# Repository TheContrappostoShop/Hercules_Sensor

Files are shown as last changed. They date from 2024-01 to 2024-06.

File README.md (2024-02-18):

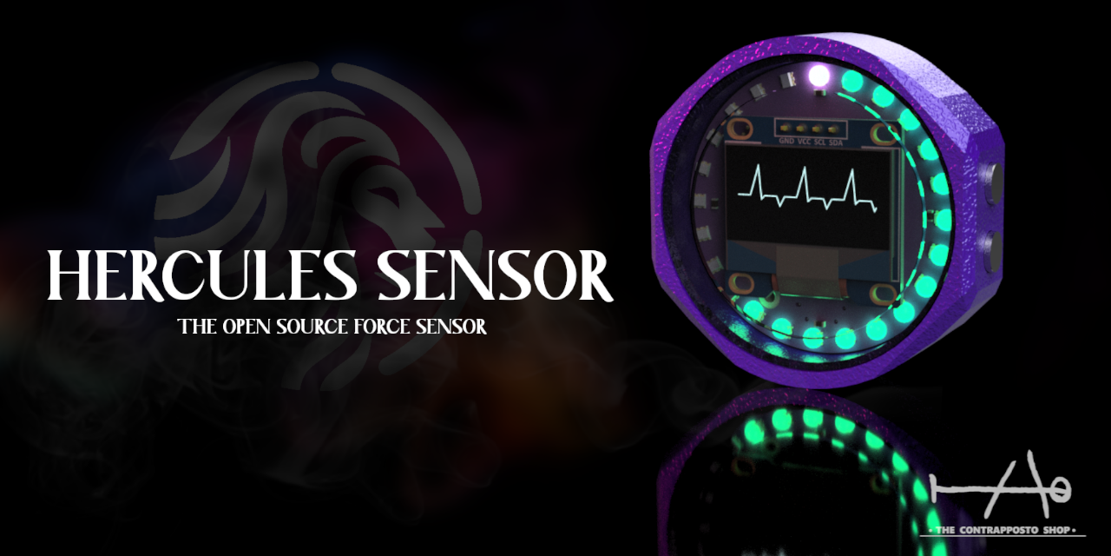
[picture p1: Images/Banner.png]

# Hercules Force Sensor Discord Link (https://discord.gg/GFUn9gwRsj)


Hercules is the open-source force sensor made for the Prometheus mSLA, based on the idea of Nico Martin (Concepts3D).

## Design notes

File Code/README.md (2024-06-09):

**This code is only for example and research purposes. It contains very simple routine to scale the graph and a simple peel detection algorithm. It can be serve to use the Hercules sensor "stand alone" because it will be integrated in our OS "Odyssey".**

How it works:

To calibrate the load cell the user needs to long press the screen then a calibration procedure will appear. A short press of the screen will zero out (tare) the current value.
After a few cycles the microcontroller will average the peak values of each peeling detection ( the number will be set at the top right corner ). The value at the top left is the real time value detected.
After a certain ammount of peel detected the scale is updated. The ''0'' value will zero out so the scale doesnt drift after a few layers of printing. It means that it will not take in account the weight of the parts on the build plate. 
The LED ring light represents the forces in real time. The 0 position represents the ''normal'' state and the end of the ring light (+100%) represents the max value of the graph (based on the average top right value).

**The peeling algorithm**

For now the few tests we did look promising even with this super simple algorithm. A threshold value is set just above the 0 line. When a peak is detected and the value returns close to 0 the peel detection is done.
*Sometimes with larger cross sections the peeling is done in stages and its probable that you will have multiple peaks. The treshold value is there so you are not detecting a wrong peel. Also there is a little waiting time (0.5sec) to see if the value is rising up signifying that the peel is not done yet.
When the sensor will be linked with Odyssey, we will be able to send commands both ways. It means that we will have something like ''wait for peel'' so the peeling will be in sink with the printer states.

User parameters Of the sensor:

-How many load cell ( if the sensor is used alone we suggest to use only one because processing all the numbers and calculations will slow down the microcontroller. Later all the calculation will be processed by Odyssey and the raspberry pi )

-Calibration factor ( Will be shown after the calibration procedure )

-Sample rate ( How many samples the microcontroller takes per second. Higher the number is the slower the microcontroller will be. )

-Display refresh rate ( How many time per second the screen will be updated. This number is also used for the simple filter to handle the noise.)

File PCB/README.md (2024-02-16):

# Top and buttom view of the PCB

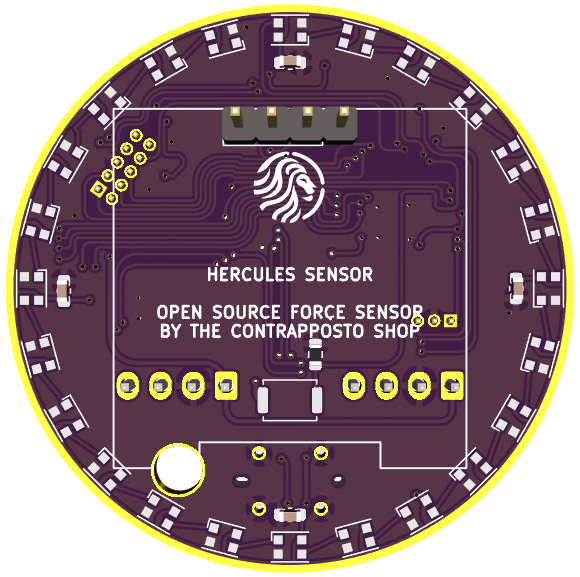
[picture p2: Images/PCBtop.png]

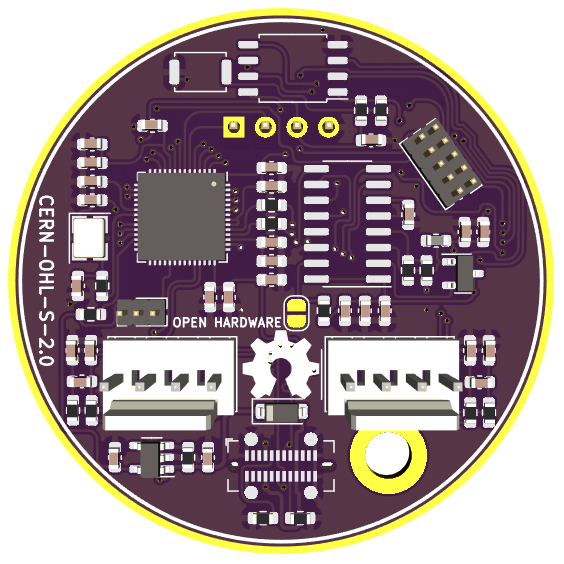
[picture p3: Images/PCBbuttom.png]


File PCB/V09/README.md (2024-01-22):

The version 0.9 of the Hercules sensor is the prerelease (beta) of it.

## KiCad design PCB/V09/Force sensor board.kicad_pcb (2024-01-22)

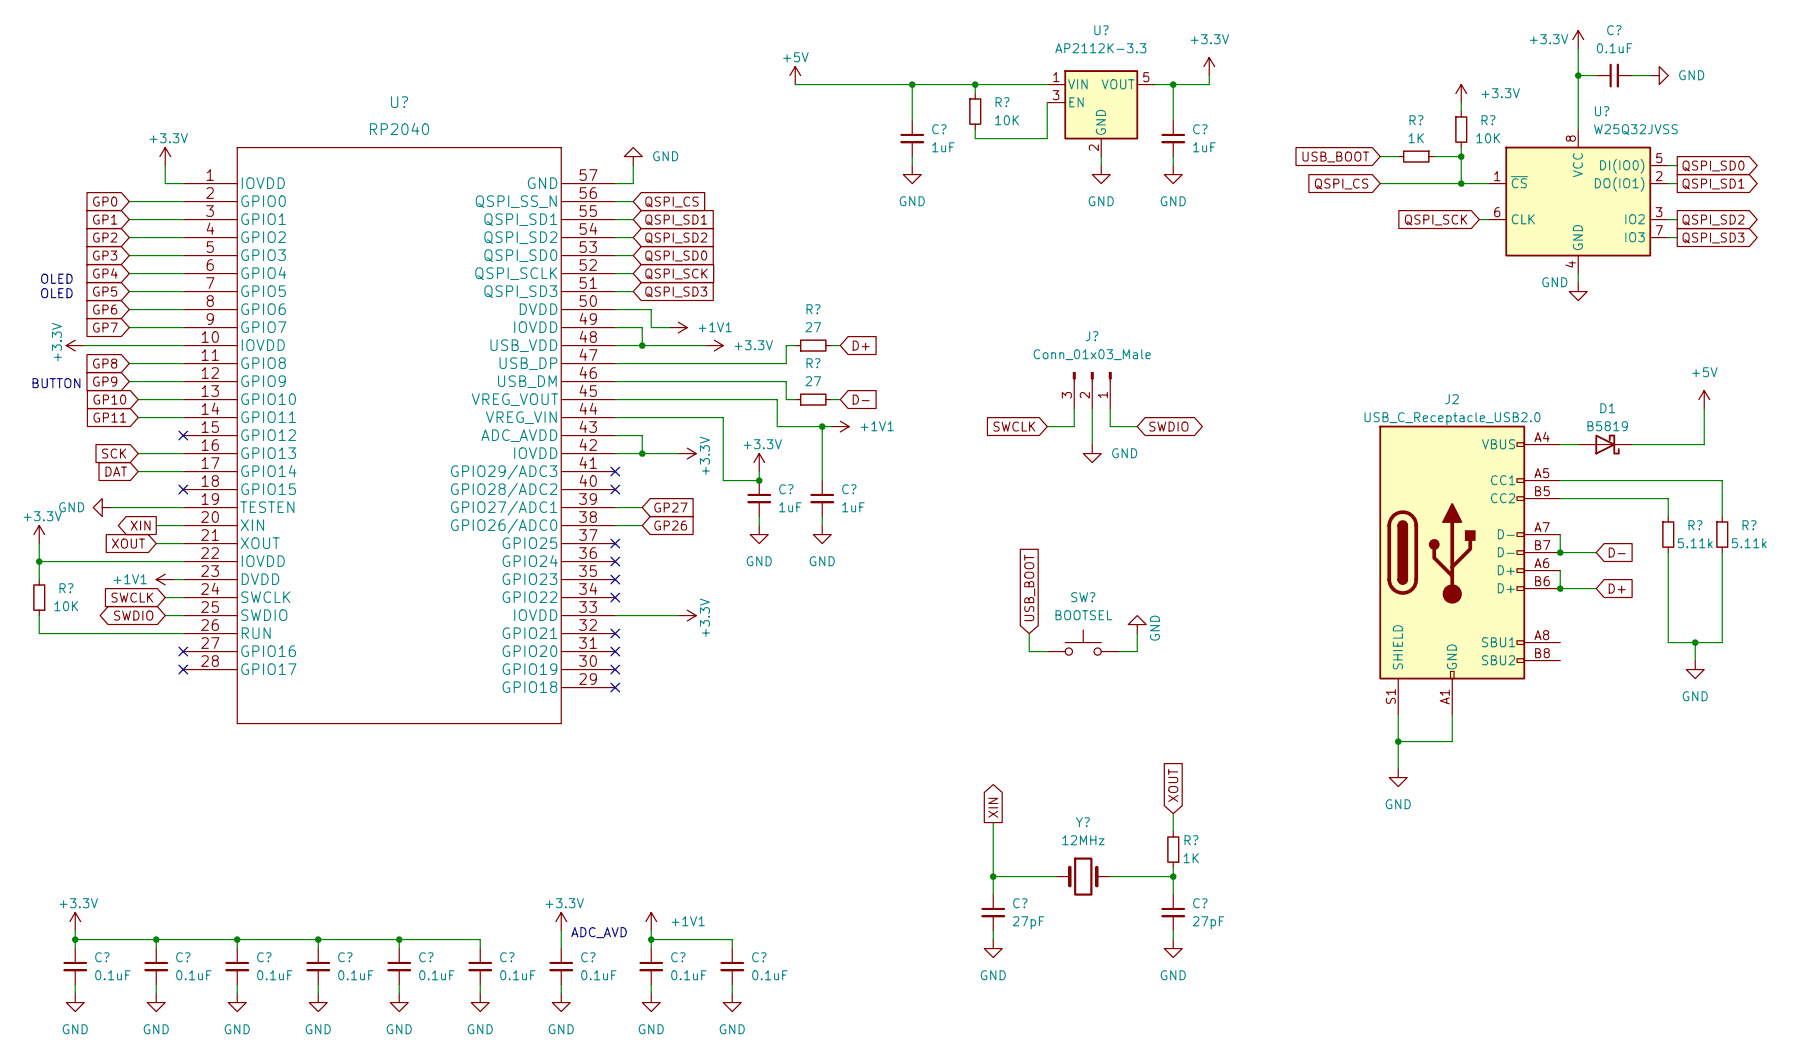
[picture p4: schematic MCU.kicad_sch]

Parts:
C1, C8, C9, C10, C11, C12, C13, C14, C15, C16: 0.1uF; C_0603_1608Metric
C2, C3, C4, C5: 1uF; C_0603_1608Metric
C6, C7: 27pF; C_0603_1608Metric
D1: B5819; D_SOD-123
J1: Conn_01x03_Male; PinHeader_1x03_P1.27mm_Vertical
J2: USB_C_Receptacle_USB2.0; USB_C_Receptacle_GCT_USB4115-03-C
R1, R2, R8: 10K; R_0603_1608Metric
R3, R9: 1K; R_0603_1608Metric
R4, R5: 27; R_0603_1608Metric
R6, R7: 5.11k; R_0603_1608Metric
SW1: BOOTSEL; SW_Push_SPST_NO_Alps_SKRK
U1: AP2112K-3.3; SOT-23-5
U2: RP2040; QFN-56-1EP_7x7mm_P0.4mm_EP3.2x3.2mm
U3: W25Q32JVSS; SOIC-8_5.23x5.23mm_P1.27mm
Y1: 12MHz; Crystal_SMD_3225-4Pin_3.2x2.5mm

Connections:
+1V1: C5.1, C15.1, C16.1, U2.23 (DVDD), U2.45 (VREG_VOUT), U2.50 (DVDD)
+3V3: C1.1, C3.1, C4.1, C8.1, C9.1, C10.1, C11.1, C12.1, C13.1, C14.1, R2.1, R8.2, U1.5 (VOUT), U2.1 (IOVDD), U2.10 (IOVDD), U2.22 (IOVDD), U2.33 (IOVDD), U2.42 (IOVDD), U2.43 (ADC_AVDD), U2.44 (VREG_VIN), U2.48 (USB_VDD), U2.49 (IOVDD), U3.8 (VCC); also elsewhere on the board
+5V: C2.1, D1.1 (K), R1.1, U1.1 (VIN); also elsewhere on the board
D+: J2.A6 (D+), J2.B6 (D+), R4.2
D-: J2.A7 (D-), J2.B7 (D-), R5.2
DAT: U2.17 (GPIO14); also elsewhere on the board
GP0: U2.2 (GPIO0); also elsewhere on the board
GP1: U2.3 (GPIO1); also elsewhere on the board
GP2: U2.4 (GPIO2); also elsewhere on the board
GP3: U2.5 (GPIO3); also elsewhere on the board
GP4: U2.6 (GPIO4); also elsewhere on the board
GP5: U2.7 (GPIO5); also elsewhere on the board
GP6: U2.8 (GPIO6); also elsewhere on the board
GP7: U2.9 (GPIO7); also elsewhere on the board
GP8: U2.11 (GPIO8); also elsewhere on the board
GP9: U2.12 (GPIO9); also elsewhere on the board
GP10: U2.13 (GPIO10)
GP11: U2.14 (GPIO11)
GP26: U2.38 (GPIO26/ADC0); also elsewhere on the board
GP27: U2.39 (GPIO27/ADC1); also elsewhere on the board
unnamed: D1.2 (A), J2.A4 (VBUS), J2.A9 (VBUS), J2.B4 (VBUS), J2.B9 (VBUS)
unnamed: J2.A5 (CC1), R7.1
unnamed: J2.B5 (CC2), R6.1
unnamed: R1.2, U1.3 (EN)
unnamed: R8.1, U2.26 (RUN)
unnamed: R5.1, U2.46 (USB_DM)
unnamed: R4.1, U2.47 (USB_DP)
unnamed: C7.1, R9.1, Y1.3 (2)
QSPI_CS: R2.2, R3.1, U2.56 (QSPI_SS_N), U3.1 (~CS)
QSPI_SCK: U2.52 (QSPI_SCLK), U3.6 (CLK)
QSPI_SD0: U2.53 (QSPI_SD0), U3.5 (DI(IO0))
QSPI_SD1: U2.55 (QSPI_SD1), U3.2 (DO(IO1))
QSPI_SD2: U2.54 (QSPI_SD2), U3.3 (IO2)
QSPI_SD3: U2.51 (QSPI_SD3), U3.7 (IO3)
SCK: U2.16 (GPIO13); also elsewhere on the board
SWCLK: J1.3, U2.24 (SWCLK)
SWDIO: J1.1, U2.25 (SWDIO)
XIN: C6.1, U2.20 (XIN), Y1.1
XOUT: R9.2, U2.21 (XOUT)

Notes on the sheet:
BUTTON
ADC_AVD
OLED OLED

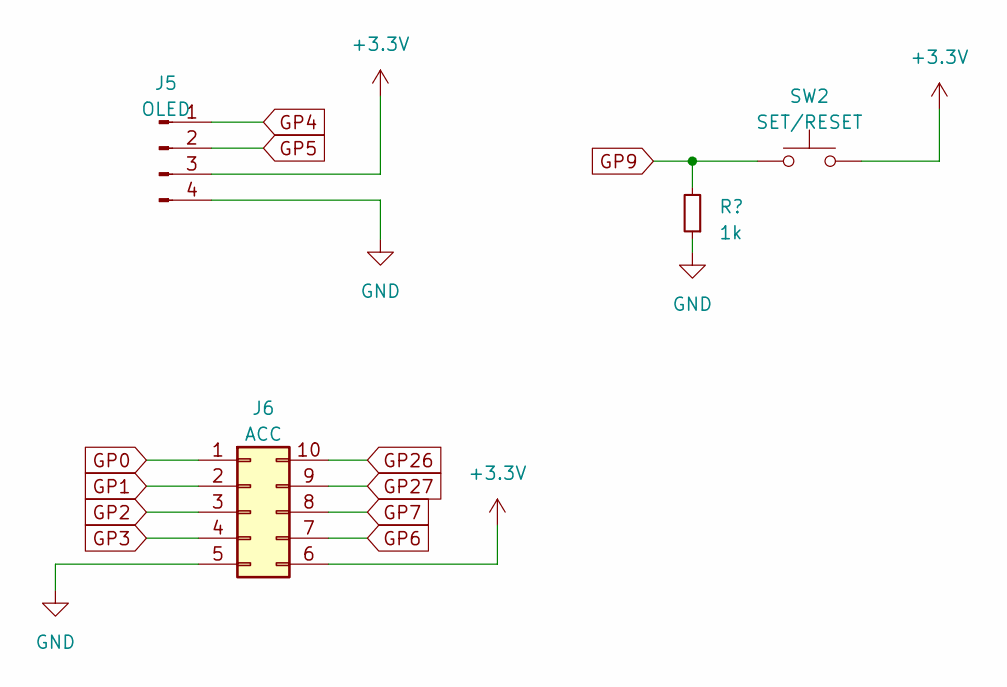
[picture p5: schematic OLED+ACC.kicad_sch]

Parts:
J5: OLED; PinHeader_1x04_P2.54mm_Vertical
J6: ACC; PinHeader_2x05_P1.27mm_Vertical
R17: 1k; R_0603_1608Metric
SW2: SET/RESET; SW_Push_SPST_NO_Alps_SKRK

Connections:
+3V3: J5.3, J6.6, SW2.2; also elsewhere on the board
GP0: J6.1; also elsewhere on the board
GP1: J6.2; also elsewhere on the board
GP2: J6.3; also elsewhere on the board
GP3: J6.4; also elsewhere on the board
GP4: J5.1; also elsewhere on the board
GP5: J5.2; also elsewhere on the board
GP6: J6.7; also elsewhere on the board
GP7: J6.8; also elsewhere on the board
GP9: R17.2, SW2.1; also elsewhere on the board
GP26: J6.10; also elsewhere on the board
GP27: J6.9; also elsewhere on the board

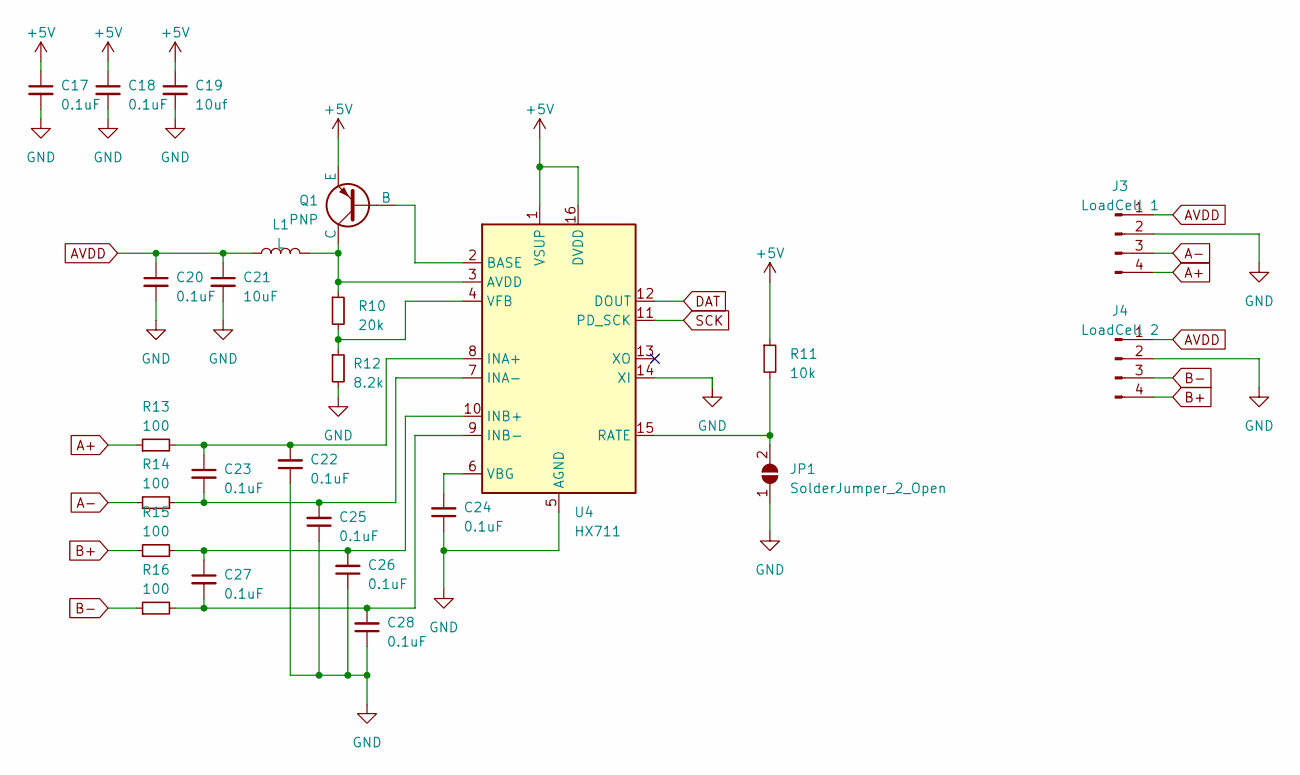
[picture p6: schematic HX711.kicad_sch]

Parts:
C17, C18, C20, C22, C23, C24, C25, C26, C27, C28: 0.1uF; C_0603_1608Metric
C19: 10uf; C_0603_1608Metric
C21: 10uF; C_0603_1608Metric
J3: LoadCell 1; Molex_KK-254_AE-6410-04A_1x04_P2.54mm_Vertical
J4: LoadCell 2; Molex_KK-254_AE-6410-04A_1x04_P2.54mm_Vertical
JP1: SolderJumper_2_Open; SolderJumper-2_P1.3mm_Open_RoundedPad1.0x1.5mm
L1: L; L_0603_1608Metric
Q1: PNP; SOT-23
R10: 20k; R_0603_1608Metric
R11: 10k; R_0603_1608Metric
R12: 8.2k; R_0603_1608Metric
R13, R14, R15, R16: 100; R_0603_1608Metric
U4: HX711; SOP-16_3.9x9.9mm_P1.27mm

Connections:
+5V: C17.1, C18.1, C19.1, Q1.3 (E), R11.1, U4.1 (VSUP), U4.16 (DVDD); also elsewhere on the board
A+: J3.4, R13.1
A-: J3.3, R14.1
AVDD: C20.1, C21.1, J3.1, J4.1, L1.1
B+: J4.4, R15.1
B-: J4.3, R16.1
DAT: U4.12 (DOUT); also elsewhere on the board
unnamed: JP1.2 (B), R11.2, U4.15 (RATE)
unnamed: Q1.2 (B), U4.2 (BASE)
unnamed: L1.2, Q1.1 (C), R10.1, U4.3 (AVDD)
unnamed: C22.2, C23.1, R13.2, U4.8 (INA+)
unnamed: C23.2, C25.2, R14.2, U4.7 (INA-)
unnamed: C26.2, C27.1, R15.2, U4.10 (INB+)
unnamed: C27.2, C28.2, R16.2, U4.9 (INB-)
unnamed: C24.2, U4.6 (VBG)
unnamed: R10.2, R12.1, U4.4 (VFB)
SCK: U4.11 (PD_SCK); also elsewhere on the board

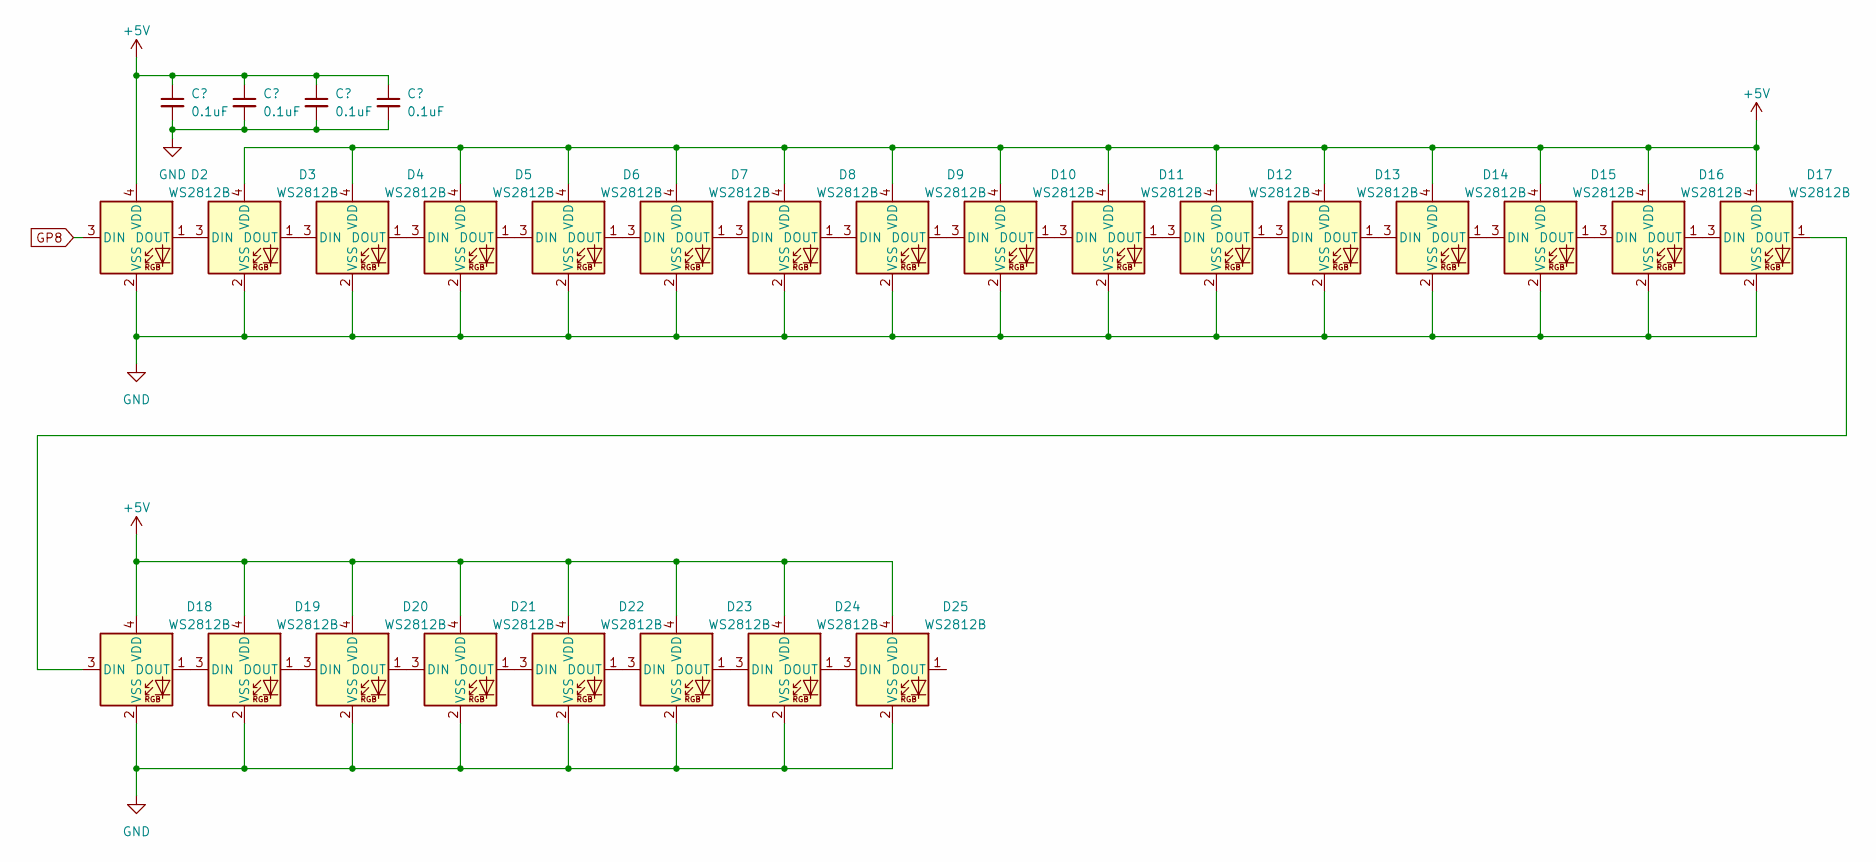
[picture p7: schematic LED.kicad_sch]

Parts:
C29, C30, C31, C32: 0.1uF; C_0603_1608Metric
D2, D3, D4, D5, D6, D7, D8, D9, D10, D11, D12, D13, D14, D15, D16, D17, D18, D19, D20, D21, D22, D23, D24, D25: WS2812B; LED_WS2812B-2020_PLCC4_2.0x2.0mm

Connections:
+5V: C29.1, C30.1, C31.1, C32.1, D2.4 (VDD), D3.4 (VDD), D4.4 (VDD), D5.4 (VDD), D6.4 (VDD), D7.4 (VDD), D8.4 (VDD), D9.4 (VDD), D10.4 (VDD), D11.4 (VDD), D12.4 (VDD), D13.4 (VDD), D14.4 (VDD), D15.4 (VDD), D16.4 (VDD), D17.4 (VDD), D18.4 (VDD), D19.4 (VDD), D20.4 (VDD), D21.4 (VDD), D22.4 (VDD), D23.4 (VDD), D24.4 (VDD), D25.4 (VDD); also elsewhere on the board
GP8: D2.3 (DIN); also elsewhere on the board
unnamed: D2.1 (DOUT), D3.3 (DIN)
unnamed: D3.1 (DOUT), D4.3 (DIN)
unnamed: D4.1 (DOUT), D5.3 (DIN)
unnamed: D5.1 (DOUT), D6.3 (DIN)
unnamed: D6.1 (DOUT), D7.3 (DIN)
unnamed: D7.1 (DOUT), D8.3 (DIN)
unnamed: D8.1 (DOUT), D9.3 (DIN)
unnamed: D9.1 (DOUT), D10.3 (DIN)
unnamed: D10.1 (DOUT), D11.3 (DIN)
unnamed: D11.1 (DOUT), D12.3 (DIN)
unnamed: D12.1 (DOUT), D13.3 (DIN)
unnamed: D13.1 (DOUT), D14.3 (DIN)
unnamed: D14.1 (DOUT), D15.3 (DIN)
unnamed: D15.1 (DOUT), D16.3 (DIN)
unnamed: D16.1 (DOUT), D17.3 (DIN)
unnamed: D17.1 (DOUT), D18.3 (DIN)
unnamed: D18.1 (DOUT), D19.3 (DIN)
unnamed: D19.1 (DOUT), D20.3 (DIN)
unnamed: D20.1 (DOUT), D21.3 (DIN)
unnamed: D21.1 (DOUT), D22.3 (DIN)
unnamed: D22.1 (DOUT), D23.3 (DIN)
unnamed: D23.1 (DOUT), D24.3 (DIN)
unnamed: D24.1 (DOUT), D25.3 (DIN)

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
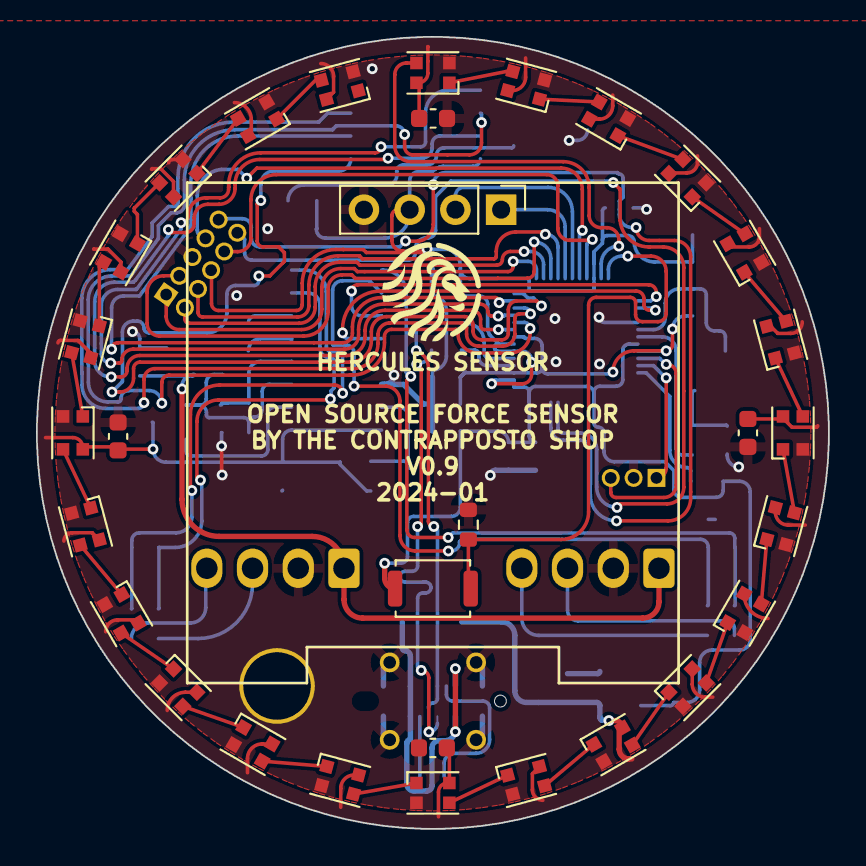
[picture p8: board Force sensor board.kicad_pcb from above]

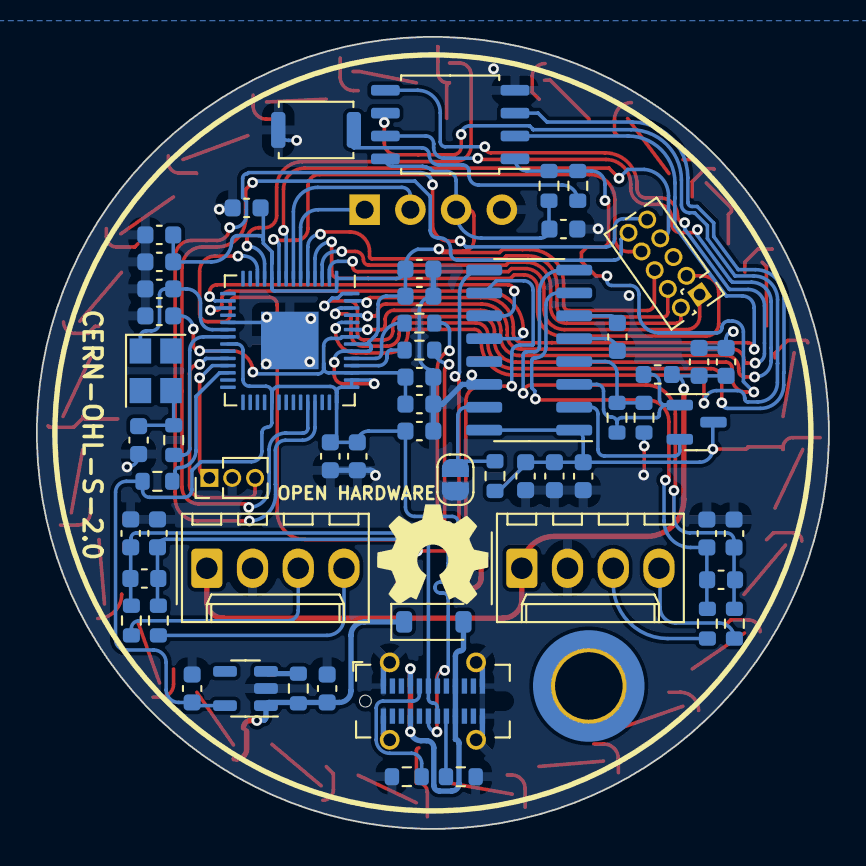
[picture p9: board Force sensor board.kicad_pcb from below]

Board: 2 copper layers, 44.0 x 44.0 mm, 90 parts (59 on the bottom side), 76 nets.

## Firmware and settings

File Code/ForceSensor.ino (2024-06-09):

#include "HX711.h"
#include <Adafruit_NeoPixel.h>
#include <Wire.h>
#include <Adafruit_GFX.h>
#include <Adafruit_SSD1306.h>
#include "PeelingDetection.h"

// OLED display width and height
#define SCREEN_WIDTH 128
#define SCREEN_HEIGHT 64

// Pin definitions
#define BUTTON_PIN 9
#define LED_PIN 8
#define LOADCELL_DOUT_PIN 14
#define LOADCELL_SCK_PIN 13

// LED configuration
#define LED_COUNT 24
Adafruit_NeoPixel strip(LED_COUNT, LED_PIN, NEO_GRB + NEO_KHZ800);

// OLED display initialization
Adafruit_SSD1306 display(SCREEN_WIDTH, SCREEN_HEIGHT, &Wire, -1);

// HX711 scale initialization
HX711 scale;

/////////////////////////////////////////////////////////
///////////////// USER DEFINED VALUES ///////////////////
////////////////////////////////////////////////////////

// Calibration factors for both channels
float calibrationFactorA = 500; // Adjust this to your specific calibration factor
float calibrationFactorB = 500; // Adjust this to your specific calibration factor

// Force thresholds
float maxPositiveForce = 300.0;
float maxNegativeForce = -300.0;

// Color settings
const uint32_t colorStartPositive = strip.Color(0, 20, 20);
const uint32_t colorEndPositive = strip.Color(0, 20, 0);
const uint32_t colorStartNegative = strip.Color(0, 0, 20);
const uint32_t colorEndNegative = strip.Color(20, 0, 0);

// Global variables to store offsets
long offsetA = 0;
long offsetB = 0;

// User-defined parameters
const int sampleRate = 60; // Samples per second
const int displayRefreshRate = 4; // Display refresh rate in Hz (also used for median smoothing)
const int numLoadCells = 1; // Number of load cells (1 or 2)
const int resolution = 20; // Scale resolution in grams
const int smoothingEnabled = 0; // Toggle for smoothing function (1 = on, 0 = off)

/////////////////////////////////////////////////////////
/////////////////////////////////////////////////////////
/////////////////////////////////////////////////////////

// Graph settings
float graphValues[SCREEN_WIDTH] = {0};
int graphIndex = 0;

// Flashing control
unsigned long flashStartTime = 0;
int flashCount = 0;
bool flashing = false;

// Variables for median smoothing
const int sampleSize = sampleRate / displayRefreshRate;
float samplesA[sampleSize];
float samplesB[sampleSize];
int sampleIndex = 0;

// Function declarations
void displayGraph(float weight);
float median(float* arr, int size);

void setup() {
  pinMode(BUTTON_PIN, INPUT);
  Serial.begin(9600);

  // Initialize scale
  scale.begin(LOADCELL_DOUT_PIN, LOADCELL_SCK_PIN);

  // Automatically tare the load cells at startup
  Serial.println("Taring the load cells...");
  scale.set_gain(128); // Select channel A
  scale.tare();
  offsetA = scale.get_offset();
  Serial.print("Offset A: ");
  Serial.println(offsetA);

  if (numLoadCells == 2) {
    scale.set_gain(32); // Select channel B
    scale.tare();
    offsetB = scale.get_offset();
    Serial.print("Offset B: ");
    Serial.println(offsetB);
  }

  // Initialize LED strip
  strip.begin();
  strip.show();

  // Initialize OLED display
  if (!display.begin(SSD1306_SWITCHCAPVCC, 0x3C)) {
    Serial.println(F("SSD1306 allocation failed"));
    for (;;);
  }
  display.clearDisplay();

  setupPeelingDetection(); // Setup peeling detection if necessary
}

float median(float* arr, int size) {
  float sorted[size];
  memcpy(sorted, arr, sizeof(float) * size);
  for (int i = 0; i < size - 1; i++) {
    for (int j = 0; j < size - i - 1; j++) {
      if (sorted[j] > sorted[j + 1]) {
        float temp = sorted[j];
        sorted[j] = sorted[j + 1];
        sorted[j + 1] = temp;
      }
    }
  }
  if (size % 2 == 0) {
    return (sorted[size / 2 - 1] + sorted[size / 2]) / 2.0;
  } else {
    return sorted[size / 2];
  }
}

void loop() {
  handleButton(); // Call function to handle button logic
  handleFlashing(); // Call this every loop iteration

  // Read weight from channel A and channel B without delays
  float weightA = 0;
  float weightB = 0;

  if (numLoadCells >= 1) {
    scale.set_gain(128); // Select channel A
    scale.set_scale(calibrationFactorA); // Apply calibration factor for channel A
    scale.set_offset(offsetA); // Apply offset for channel A
    weightA = scale.get_units(1); // Read weight from channel A
    if (smoothingEnabled) {
      samplesA[sampleIndex] = weightA;
    }
  }

  if (numLoadCells == 2) {
    scale.set_gain(32);  // Select channel B
    scale.set_scale(calibrationFactorB); // Apply calibration factor for channel B
    scale.set_offset(offsetB); // Apply offset for channel B
    weightB = scale.get_units(1); // Read weight from channel B
    if (smoothingEnabled) {
      samplesB[sampleIndex] = weightB;
    }
  }

  if (smoothingEnabled) {
    sampleIndex = (sampleIndex + 1) % sampleSize;

    if (sampleIndex == 0) {
      // Calculate the median of the samples
      float medianA = numLoadCells >= 1 ? median(samplesA, sampleSize) : 0;
      float medianB = numLoadCells == 2 ? median(samplesB, sampleSize) : 0;

      // Calculate the average weight
      float weight = (medianA + medianB) / numLoadCells;

      // Apply resolution
      weight = round(weight / resolution) * resolution;

      // Update LEDs, detect peeling, and update the graph with the average weight
      updateLEDs(weight);
      detectPeel(weight);

      // Update the graph with the new weight value
      displayGraph(weight);

      if (peelDetectedFlag) {
        flashPeelDetected();
        peelDetectedFlag = false;
      }

      // Print average weight to the serial monitor for debugging
      Serial.print("Weight A: ");
      Serial.print(weightA, 0); // Print without decimals
      if (numLoadCells == 2) {
        Serial.print(" g, Weight B: ");
        Serial.print(weightB, 0); // Print without decimals
      }
      Serial.print(" g, Average Weight: ");
      Serial.print(weight, 0); // Print without decimals
      Serial.println(" g");
    }
  } else {
    // Calculate the average weight without smoothing
    float weight = (weightA + weightB) / numLoadCells;

    // Apply resolution
    weight = round(weight / resolution) * resolution;

    // Update LEDs, detect peeling, and update the graph with the average weight
    updateLEDs(weight);
    detectPeel(weight);

    // Update the graph with the new weight value
    displayGraph(weight);

    if (peelDetectedFlag) {
      flashPeelDetected();
      peelDetectedFlag = false;
    }

    // Print average weight to the serial monitor for debugging
    Serial.print("Weight A: ");
    Serial.print(weightA, 0); // Print without decimals
    if (numLoadCells == 2) {
      Serial.print(" g, Weight B: ");
      Serial.print(weightB, 0); // Print without decimals
    }
    Serial.print(" g, Average Weight: ");
    Serial.print(weight, 0); // Print without decimals
    Serial.println(" g");
  }

  delay(1000 / sampleRate); // Sample rate control
}

// Function to handle button presses
void handleButton() {
  static unsigned long pressTime = 0;
  static bool isPressing = false;
  static bool isLongPress = false;

  bool currentButtonState = digitalRead(BUTTON_PIN); // Read the button (active high with pull-down)

  if (currentButtonState && !isPressing) {
    isPressing = true;
    pressTime = millis();
    isLongPress = false;
  } else if (!currentButtonState && isPressing) {
    if (isLongPress) {
      performCalibration();
    } else {
      resetGraphAndZeroWeight();
    }
    isPressing = false;
  } else if (isPressing && (millis() - pressTime > 2000)) {
    isLongPress = true;
  }
}

// Function to reset the graph and tare the scale
void resetGraphAndZeroWeight() {
  for (int i = 0; i < SCREEN_WIDTH; i++) {
    graphValues[i] = 0;
  }
  graphIndex = 0;

  // Zero both scales
  scale.set_gain(128); // Select channel A
  scale.tare(); // Zero channel A
  offsetA = scale.get_offset();

  if (numLoadCells == 2) {
    scale.set_gain(32); // Select channel B
    scale.tare(); // Zero channel B
    offsetB = scale.get_offset();
  }

  displayGraph(0);
}

// Function to update the LEDs based on the weight
void updateLEDs(float weight) {
  int ledToLight;
  uint32_t color;

  for (int i = 0; i < LED_COUNT; i++) {
    strip.setPixelColor(i, strip.Color(0, 0, 0));
  }

  strip.setPixelColor(0, strip.Color(50, 50, 50));

  if (weight >= 0) {
    ledToLight = map(weight, 0, maxPositiveForce, 0, LED_COUNT);
    color = blend(colorStartPositive, colorEndPositive, weight, maxPositiveForce);
    for (int i = 1; i < ledToLight; i++) {
      strip.setPixelColor(i, color);
    }
  } else {
    ledToLight = map(abs(weight), 0, abs(maxNegativeForce), 0, LED_COUNT);
    color = blend(colorStartNegative, colorEndNegative, abs(weight), abs(maxNegativeForce));
    for (int i = LED_COUNT - ledToLight; i < LED_COUNT; i++) {
      if (i != 0) {
        strip.setPixelColor(i, color);
      }
    }
  }

  strip.show();
}

// Function to blend colors for the LEDs
uint32_t blend(uint32_t colorStart, uint32_t colorEnd, float currentForce, float maxForce) {
  float ratio = currentForce / maxForce;
  ratio = max(0.0f, min(ratio, 1.0f));

  int red = ((uint8_t)(colorEnd >> 16) * ratio) + ((uint8_t)(colorStart >> 16) * (1 - ratio));
  int green = ((uint8_t)(colorEnd >> 8) * ratio) + ((uint8_t)(colorStart >> 8) * (1 - ratio));
  int blue = ((uint8_t)colorEnd * ratio) + ((uint8_t)colorStart * (1 - ratio));

  return strip.Color(red, green, blue);
}

// Function to flash LEDs when peel is detected
void flashPeelDetected() {
  if (!flashing) {
    flashing = true;
    flashCount = 0;
    flashStartTime = millis();
    strip.setPixelColor(0, strip.Color(0, 255, 0));
    strip.show();
  }
}

// Function to handle flashing LEDs
void handleFlashing() {
  if (flashing) {
    unsigned long currentTime = millis();
    if (currentTime - flashStartTime > 50) {
      flashStartTime = currentTime;
      if (flashCount % 2 == 0) {
        strip.setPixelColor(0, strip.Color(0, 0, 0));
      } else {
        strip.setPixelColor(0, strip.Color(0, 255, 0));
      }
      strip.show();
      flashCount++;
      if (flashCount >= 3) {
        flashing = false;
        strip.setPixelColor(0, strip.Color(0, 0, 0));
        strip.show();
      }
    }
  }
}

// Function to display the graph on the OLED
void displayGraph(float weight) {
    // Shift all graph values to the left
    for (int i = 0; i < SCREEN_WIDTH - 1; i++) {
        graphValues[i] = graphValues[i + 1];
    }

    // Add the new weight value to the end of the array
    graphValues[SCREEN_WIDTH - 1] = weight;

    // Clear the display
    display.clearDisplay();

    // Determine the dynamic range of the graph
    float maxGraphValue = maxPositiveForce;
    float minGraphValue = maxNegativeForce;
    for (int i = 0; i < SCREEN_WIDTH; i++) {
        if (graphValues[i] > maxGraphValue) {
            maxGraphValue = graphValues[i];
        }
        if (graphValues[i] < minGraphValue) {
            minGraphValue = graphValues[i];
        }
    }

    // Ensure the graph accommodates both positive and negative peaks
    float graphUpperBound = max(maxGraphValue, -minGraphValue);
    float graphLowerBound = -graphUpperBound;

    // Draw the graph
    for (int i = 0; i < SCREEN_WIDTH - 1; i++) {
        int x1 = i;
        int y1 = map(graphValues[i], graphLowerBound, graphUpperBound, SCREEN_HEIGHT, 0);
        int x2 = i + 1;
        int y2 = map(graphValues[i + 1], graphLowerBound, graphUpperBound, SCREEN_HEIGHT, 0);
        display.drawLine(x1, y1, x2, y2, WHITE);
    }

    // Display the current weight in the top left corner of the OLED
    display.setTextSize(1);
    display.setTextColor(WHITE);
    display.setCursor(0, 0);
    display.print(weight, 0);
    display.print("g");

    // Display maxPositiveForce in the top right corner of the OLED
    String maxForceStr = String(maxPositiveForce, 0) + "g";
    int maxForceWidth = (maxForceStr.length() + 1) * 6; // Approx width of text
    display.setCursor(SCREEN_WIDTH - maxForceWidth, 0); // Set cursor to top right corner
    display.print(maxForceStr);

    // Update the display with everything we've drawn
    display.display();
}

// Function to perform calibration for both channels with LED effects
void performCalibration() {
    display.clearDisplay();
    display.setTextSize(1); // Set larger font size for calibration text
    display.setCursor(0, 10); // Adjust cursor to center the text
    display.println("EMPTY");
    display.setCursor(0, 30); // Adjust for next line
    display.println("SCALE");
    display.setCursor(0, 50); // Adjust for next line
    display.println("PRESS SCREEN");
    display.display();

    // Start rainbow effect
    while (digitalRead(BUTTON_PIN) != HIGH) {
      rainbowEffect();
      delay(20); // Adjust this delay for rainbow speed
    }
    delay(500); // Debounce delay

    // Wait for 3 seconds to allow scale to stabilize
    startCountdownEffect();
    delay(3000);

    // Zero both scales
    Serial.println("Zeroing the scales...");
    scale.set_gain(128); // Select channel A
    scale.tare(); // Zero channel A
    offsetA = scale.get_offset();
    Serial.print("Offset A after tare: ");
    Serial.println(offsetA);

    if (numLoadCells == 2) {
      scale.set_gain(32); // Select channel B
      scale.tare(); // Zero channel B
      offsetB = scale.get_offset();
      Serial.print("Offset B after tare: ");
      Serial.println(offsetB);
    }

    display.clearDisplay();
    display.setCursor(0, 10); // Adjust cursor to center the text
    display.println("PLACE");
    display.setCursor(0, 30); // Adjust for next line
    display.println("1000g");
    display.setCursor(0, 50); // Adjust for next line
    display.println("PRESS SCREEN");
    display.display();

    // Start rainbow effect
    while (digitalRead(BUTTON_PIN) != HIGH) {
      rainbowEffect();
      delay(20); // Adjust this delay for rainbow speed
    }
    delay(500); // Debounce delay

    // Wait for 3 seconds to allow scale to stabilize
    startCountdownEffect();
    delay(3000);

    // Read raw values before calibration for both channels
    scale.set_gain(128); // Select channel A
    float readingA = scale.get_units(10);
    Serial.print("Reading A before calibration: ");
    Serial.println(readingA);

    if (numLoadCells == 2) {
      scale.set_gain(32); // Select channel B
      float readingB = scale.get_units(10);
      Serial.print("Reading B before calibration: ");
      Serial.println(readingB);
    }

    // Assuming you use a 1000g weight for calibration
    scale.set_gain(128); // Select channel A
    scale.calibrate_scale(1000.0, 10); // Calibrate with the known weight for channel A
    calibrationFactorA = scale.get_scale();
    Serial.print("Calibration factor A: ");
    Serial.println(calibrationFactorA);

    if (numLoadCells == 2) {
      scale.set_gain(32); // Select channel B
      scale.calibrate_scale(1000.0, 10); // Calibrate with the known weight for channel B
      calibrationFactorB = scale.get_scale();
      Serial.print("Calibration factor B: ");
      Serial.println(calibrationFactorB);
    }

    display.clearDisplay();
    display.setCursor(0, 20); // Adjust cursor to center the text
    display.println("CALIBRATION");
    display.setCursor(0, 40); // Adjust for next line
    display.println("COMPLETE!");

    // Display the calibration factors
    display.setCursor(0, 50);
    display.print("A: ");
    display.print(calibrationFactorA);
    if (numLoadCells == 2) {
      display.print(" B: ");
      display.print(calibrationFactorB);
    }
    display.display();
    
    delay(2000); // Show completion message

    // Verify Calibration
    Serial.println("Verifying Calibration...");

    // Check channel A
    scale.set_gain(128); // Select channel A
    scale.set_scale(calibrationFactorA); // Apply calibration factor for channel A
    scale.set_offset(offsetA); // Apply offset for channel A
    float weightA = scale.get_units(10);
    Serial.print("Weight A after calibration: ");
    Serial.println(weightA);

    if (numLoadCells == 2) {
      // Check channel B
      scale.set_gain(32); // Select channel B
      scale.set_scale(calibrationFactorB); // Apply calibration factor for channel B
      scale.set_offset(offsetB); // Apply offset for channel B
      float weightB = scale.get_units(10);
      Serial.print("Weight B after calibration: ");
      Serial.println(weightB);
    }
}

// Function to display a rainbow effect on the LED ring
void rainbowEffect() {
  static uint16_t j = 0;
  for (int i = 0; i < LED_COUNT; i++) {
    strip.setPixelColor(i, Wheel((i + j) & 255));
  }
  strip.show();
  j++;
}

// Function to generate rainbow colors across 0-255 positions
uint32_t Wheel(byte WheelPos) {
  WheelPos = 255 - WheelPos;
  uint8_t brightnessFactor = 40; // Adjust this value (0-255) to set brightness; 128 is 50% brightness
  if (WheelPos < 85) {
    return strip.Color((255 - WheelPos * 3) * brightnessFactor / 255, 0, (WheelPos * 3) * brightnessFactor / 255);
  }
  if (WheelPos < 170) {
    WheelPos -= 85;
    return strip.Color(0, (WheelPos * 3) * brightnessFactor / 255, (255 - WheelPos * 3) * brightnessFactor / 255);
  }
  WheelPos -= 170;
  return strip.Color((WheelPos * 3) * brightnessFactor / 255, (255 - WheelPos * 3) * brightnessFactor / 255, 0);
}

// Function to start the countdown effect
void startCountdownEffect() {
  // Clear the LEDs first
  for (int i = 0; i < LED_COUNT; i++) {
    strip.setPixelColor(i, strip.Color(0, 0, 0));
  }
  strip.show();
  delay(500); // Short delay to ensure LEDs are cleared

  // Fill LEDs sequentially
  for (int i = 0; i < LED_COUNT; i++) {
    strip.setPixelColor(i, strip.Color(60, 0, 0));
    strip.show();
    delay(125); // 3 seconds / 24 LEDs = 125ms per LED
  }
}

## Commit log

2024-01-22 Create PCB
2024-01-22 adding the kicad project files
    [Force sensor board.kicad_pcb, Force sensor board.kicad_sch, HX711.kicad_sch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]
2024-01-22 Delete PCB/Code directory
    wrong path
    [ForceSensor.ino]
2024-02-16 Rename PCB buttom.png to PCBbuttom.png
2024-02-16 Rename PCB top.png to PCBtop.png
2024-05-31 Update code
    more advance LED status, calibration and settings

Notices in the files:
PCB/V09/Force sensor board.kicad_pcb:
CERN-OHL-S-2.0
